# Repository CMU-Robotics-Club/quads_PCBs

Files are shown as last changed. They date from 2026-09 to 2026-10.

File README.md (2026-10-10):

# quads_PCBs

PCB designs for Laika, the CMU Robotics Club quadruped. Software lives in
[Laika-Software](https://github.com/CMU-Robotics-Club/Laika-Software).

Firmware lives in [quads_firmware](https://github.com/CMU-Robotics-Club/quads_firmware/tree/main). This repo might move to there into a subfolder

EDA tool: **KiCad**.

> [!IMPORTANT]
> Install git lfs: `sudo apt install git-lfs` or `brew install git-lfs`
> Run `git pull && git lfs lock Quads_MCU_PCB/*` when you want to edit the pcb, make your changes and push them, and then run `git lfs unlock Quads_MCU_PCB/*`. 
>
> This ensures that only 1 person can edit the pcb at a time. **REMEMBER TO PULL FROM REMOTE BEFORE YOU START WORKING, AND RELEASE THE LOCK WHEN YOU FINISH WORKING AND PUSH** 
>
> If you don't release the lock, we may forcefully retrieve the lock, causing your local changes to be broken and unpushable.

## System overview

TODO

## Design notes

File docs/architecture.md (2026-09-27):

# Mainboard architecture

Status: **draft**.

## Scope

The mainboard replaces the Nucleo-H723ZG and breakout modules with one PCB:

- STM32H723 MCU
- 3 CAN buses to the motors (on-chip FDCAN1–3), with CAN-FD capable
  transceivers (≥ 5 Mbps)
- USB to the Jetson Orin Nano
- IMU
- E-stop / power switch input
- Power: its own supply from the battery (5 V / 3.3 V), not from the Jetson

Not on this board: the motors, the Jetson, and motor power. Motors get power
straight from the battery.

## Motors

- 12× CubeMars AK80-8 KV30 motors, 3 per leg
- Each motor has an ODrive S1 driver
- Protocol: ODrive CAN, classic CAN frames
  ([code](https://github.com/CMU-Robotics-Club/Laika-Software/blob/dd9dcf645790c05628127b254bd854ea58fc05dc/laika_ws/src/laika_hardware_interface/odrive_base/src/socket_can.cp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)),
  1 Mbps
  ([code](https://github.com/CMU-Robotics-Club/Laika-Software/blob/dd9dcf645790c05628127b254bd854ea58fc05dc/laika_ws/src/laika_hardware_interface/hardware/laika_hardware_inter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))
- ODrive S1 supports CAN-FD from firmware 0.6.10
  ([ODrive docs](https://docs.odriverobotics.com/v/latest/hardware/odrive-comparison.html)).
  Laika-Software currently uses classic CAN.

## Control rate

**1 kHz.** [Laika-Software](https://github.com/CMU-Robotics-Club/Laika-Software)
runs its controllers at
[`update_rate: 1000`](https://github.com/CMU-Robotics-Club/Laika-Software/blob/dd9dcf645790c05628127b254bd854ea58fc05dc/laika_ws/src/laika_pid_controller/config/real_leg_pid_controller_co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).

Every cycle, for each motor:

- Host sends 3 frames:
  [`Set_Input_Torque`](https://github.com/CMU-Robotics-Club/Laika-Software/blob/dd9dcf645790c05628127b254bd854ea58fc05dc/laika_ws/src/laika_hardware_interface/hardware/laika_hardware_inter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) (torque command),
  [`Get_Torques`](https://github.com/CMU-Robotics-Club/Laika-Software/blob/dd9dcf645790c05628127b254bd854ea58fc05dc/laika_ws/src/laika_hardware_interface/hardware/laika_hardware_inter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) and
  [`Get_Encoder_Estimates`](https://github.com/CMU-Robotics-Club/Laika-Software/blob/dd9dcf645790c05628127b254bd854ea58fc05dc/laika_ws/src/laika_hardware_interface/hardware/laika_hardware_inter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) (requests)
- Host receives 2 replies: torque, and position/velocity
  ([code](https://github.com/CMU-Robotics-Club/Laika-Software/blob/dd9dcf645790c05628127b254bd854ea58fc05dc/laika_ws/src/laika_hardware_interface/hardware/laika_hardware_inter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))

The ODrive also sends `Heartbeat` frames ([code](https://github.com/CMU-Robotics-Club/Laika-Software/blob/dd9dcf645790c05628127b254bd854ea58fc05dc/laika_ws/src/laika_hardware_interface/hardware/laika_hardware_inter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)) at a rate set in
the ODrive config.

## CAN bus plan

Grouped by joint type, 4 motors per bus:

| Bus | Controller | Motors |
|---|---|---|
| CAN1 | FDCAN1 | 4× hip ab/ad (one per leg) |
| CAN2 | FDCAN2 | 4× thigh |
| CAN3 | FDCAN3 | 4× knee |

Wiring: each bus runs from motor to motor in a chain, with a 120 Ω resistor
at both ends (one on this board, one at the last motor).

## Jetson link

USB Full-Speed.

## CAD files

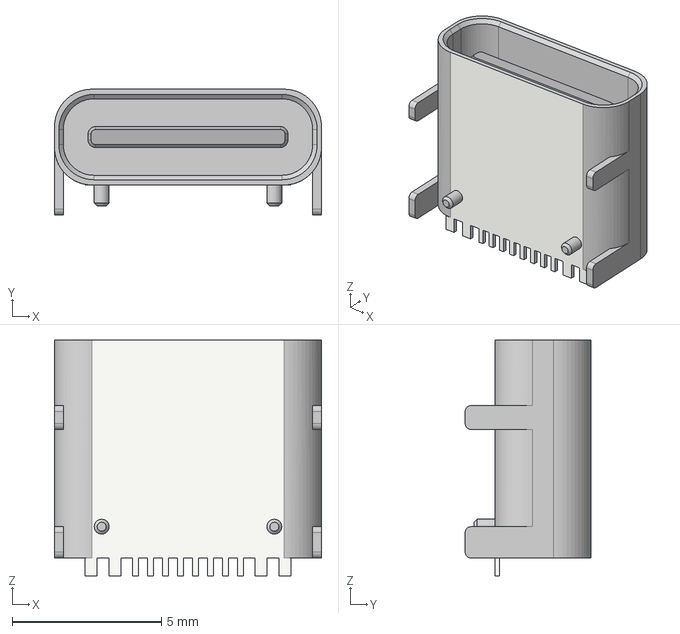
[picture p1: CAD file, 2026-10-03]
Quads_MCU_PCB/3d_models/USB_C_Receptacle_HRO_TYPE-C-31-M-12.step
8.94 x 4.21 x 7.90 mm

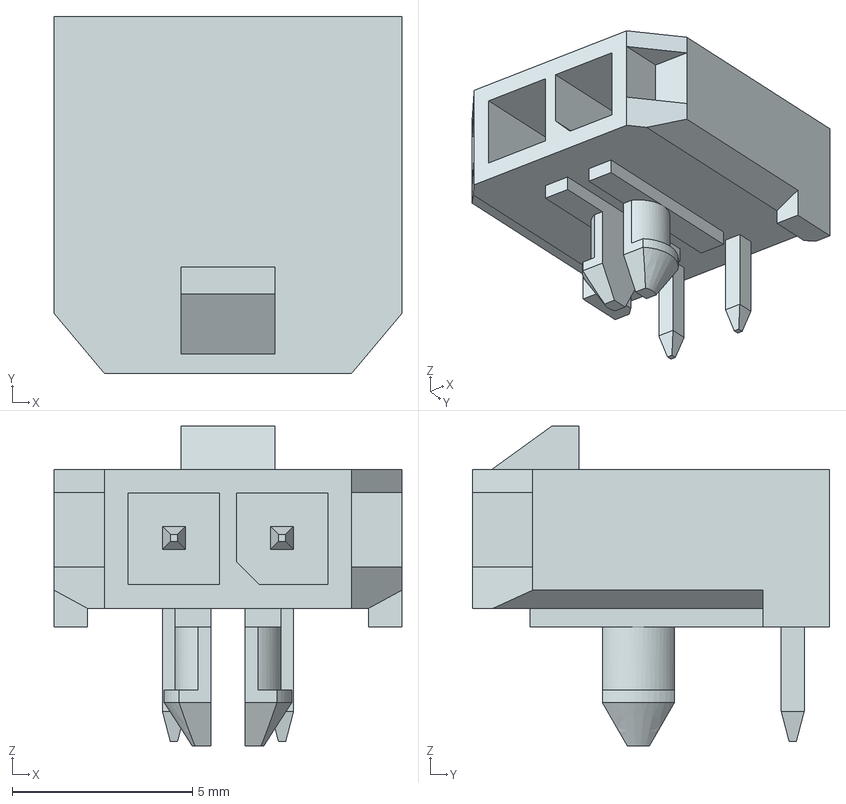
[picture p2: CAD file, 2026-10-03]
Quads_MCU_PCB/3d_models/436500200.stp
9.65 x 9.90 x 8.87 mm

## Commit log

2026-09-27 Add mainboard architecture spec and repo scaffold
    - README with board list and system block diagram
    - docs/architecture.md: 3 CAN buses grouped by joint type (4x AK80-8
    per bus, classic CAN 1 Mbps, 500 Hz), MCP2518FD footprint reserved,
    open questions
    - KiCad .gitignore
2026-09-27 Drop reserved 4th CAN bus; 3 on-chip FDCAN at 500 Hz is sufficient
2026-09-27 Correct target control rate to 1 kHz
    The 500 Hz target was derived from bus bandwidth and justified by assuming
    MIT-mode PD inside the motor. Laika-Software actually runs controllers at
    update_rate: 1000 with host-side PID sending torque every cycle, and uses
    the ODrive CAN protocol. Mark the 3-bus plan as not meeting 1 kHz and the
    motor driver/protocol as unconfirmed.
2026-09-27 Remove MIT mode assumption; state frame-count assumption explicitly
2026-09-27 Phrase CAN-FD support as open question; drop duplicate frame-count line
2026-09-27 Rewrite architecture doc in plain language, confirmed facts only
    - Motors use ODrive drivers (ODrive CAN, classic frames, 1 Mbps)
    - Control rate 1 kHz with per-cycle frame list linked to source
    - Remove estimates and open questions
2026-09-27 Keep only code-confirmed frames; drop inferred replies
2026-09-27 Specify ODrive S1 drivers and CAN-FD capable transceivers
    - ODrive S1 supports CAN-FD from firmware 0.6.10 (ODrive docs)
    - Require CAN-FD transceivers so the board works with classic CAN now
    and CAN-FD later without a respin
2026-09-27 Document received frames per cycle and ODrive heartbeat
2026-10-01 Added board
    [Quads_MCU_PCB.kicad_pcb, Quads_MCU_PCB.kicad_sch]
2026-10-01 Replaced tcan4550 with MCP2518FD
    [Quads_MCU_PCB.kicad_sch]
2026-10-01 Added CAN Connectors
    [Quads_MCU_PCB.kicad_sch]
2026-10-01 Fixed the quartz clock
    [Quads_MCU_PCB.kicad_sch]
2026-10-01 Fixed some wiring issues
    [Quads_MCU_PCB.kicad_sch]
2026-10-02 Fixed CAN pin connections
    [Quads_MCU_PCB.kicad_sch]
2026-10-02 Fixed VBUS voltage divider
    [Quads_MCU_PCB.kicad_sch]
2026-10-02 Switched to active oscillators and added MCU clock
    [Quads_MCU_PCB.kicad_sch]
2026-10-02 Fixed ERC tests
    [Quads_MCU_PCB.kicad_sch]
2026-10-02 Removed old text
    [Quads_MCU_PCB.kicad_sch]
2026-10-02 Add BMI088 IMU on SPI4
    U10 BMI088 (Sensor_Motion:BMI088, Bosch LGA-16) wired per datasheet
    Fig. 8 (SPI mode):
    - SPI4: PE2 SCK, PE5 MISO (SDO1 + SDO2), PE6 MOSI
    - Chip selects as GPIO: PE3 -> CSB1 (accel), PE4 -> CSB2 (gyro)
    - Data-ready interrupts: PE7 <- INT1 (accel), PE8 <- INT3 (gyro)
    - PS tied to GND (selects SPI); INT2/INT4 left unconnected
    - C59/C60 100nF decoupling on VDD/VDDIO, both from +3V3
    - Removed the no-connect flags on PE2-PE8
    SPI4 is separate from SPI1 so IMU reads don't compete with MCP2518FD
    CAN traffic. ERC adds one expected pin_to_pin error: SDO1/SDO2 are both
    "output" but tri-state when their CS is high, as in Bosch Fig. 8.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
    [Quads_MCU_PCB.kicad_sch]
2026-10-02 Assign footprints and LCSC part numbers for JLC assembly
    0402 for small passives, 0603 for 4.7uF/10uF, 1206 for 47uF on 5V
    rails, 1210 25V for C27 on +12V. Polyfuse is 1812 33V (1206 polyfuses
    are only rated 6-8V). Added a hidden "LCSC" field per part; every
    number was checked on jlcpcb.com (value, voltage, package,
    basic/extended).
    Not yet assigned:
    - J2-J7 connectors (J4-J7 to become JST GH 4-pin to match ODrive S1)
    - U3/U6/U7/U9 ISOW1044: out of stock at JLC
    - Y1/Y2 oscillators, SW1
    Netlist connectivity verified unchanged before/after.
    [Quads_MCU_PCB.kicad_sch]
2026-10-02 Switch CAN connectors J4-J7 to JST GH 4-pin to match ODrive S1
    ODrive S1 J16/J17 is JST GH 4-pin (SM04B-GHS-TB). Pinout from the S1
    datasheet: 1 = 12V IN (optional logic power), 2 = CAN_H, 3 = CAN_L,
    4 = GND (not connected inside the ODrive). Matching it lets us use
    straight 1:1 GH cables.
    New pinout on J4-J7:
    - Pin 1: NC (ODrive's 12V IN; we don't supply CAN power)
    - Pin 2: CANH
    - Pin 3: CANL
    - Pin 4: GND2 (isolated side of the ISOW1044, so CAN stays
    galvanically isolated from the main board)
    Footprint JST_GH_SM04B-GHS-TB_1x04-1MP_P1.25mm_Horizontal, LCSC
    C189895. The symbol was flipped and shifted so the existing wires are
    unchanged; netlist verified: only the J4-J7 pin numbers changed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
    [Quads_MCU_PCB.kicad_sch]
2026-10-02 Assign footprints for J3 power input and J2 SWD header
    - J3 (12V in): Molex Micro-Fit 3.0 43045-0212, 2x01 vertical THT with
    pegs, as Advaith picked Micro-Fit 3.0. Pad 1 = 12V in, pad 2 = GND.
    LCSC C293362 (genuine Molex).
    - J2 (SWD): generic 2.54mm 1x6 vertical header for now, since the
    debugger isn't chosen yet; jumpers fit any probe. LCSC C492405.
    Every part now has a footprint. Still missing LCSC numbers: U3/U6/U7/U9
    (ISOW1044, out of stock at JLC), Y1/Y2, SW1.
    [Quads_MCU_PCB.kicad_sch]
2026-10-02 Add LCSC part numbers for Y1, Y2 and SW1
    Y1 40 MHz: C2831396 (YXC OT322540MJBA4SL)
    Y2 25 MHz: C669088 (YXC OT322525MJBA4SL)
    3.3 V CMOS, 3225 4-pin, duty cycle 45-55% per datasheet
    (MCP2518FD requires 45-55% on OSC1). Pinout matches the ASE footprint.
    SW1: C273528 (E-Switch TL3301NF260QG), matches the TL3301NxxxxxG footprint.
    KiCad also re-sorted no_connect entries on save; no other changes.
    [Quads_MCU_PCB.kicad_sch]
2026-10-02 Replace out-of-stock ISOW1044 with ADM3057E on all four CAN channels
    ISOW1044 is out of stock at TI until 2027. ADM3057ExRW (3 kV, SOIC-20W,
    LCSC C658109) is pin-compatible enough to swap in place on U3/U6/U7/U9.
    Per channel, following the ADM3055E/ADM3057E datasheet:
    - SILENT, STBY, AUXIN tied to GND; AUXOUT not connected
    - RS tied to GND2 (full-speed mode)
    - Ferrite beads (BLM15HD182SN1D, C76888) between VISOOUT/VISOIN and
    GNDISO/GND2 to contain the 180 MHz isoPower switching noise
    - Decoupling: VCC 10u+100n, VIO 100n+10n, VISOIN 100n+10n,
    VISOOUT 10u+220n returned to GNDISO (local label <U>_GNDISO)
    New parts: C61-C68, FB1-FB8. Netlist checked per channel: TXD/RXD,
    CANH/CANL and J pi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
    [Quads_MCU_PCB.kicad_sch]
2026-10-02 Fixed ERC output pin issue
    [Quads_MCU_PCB.kicad_sch]
2026-10-02 Fixed debug pin order
    [Quads_MCU_PCB.kicad_sch]
2026-10-02 Added a debug led to PE1
    [Quads_MCU_PCB.kicad_sch]
2026-10-02 did some layout stuff
    [Quads_MCU_PCB.kicad_pcb]
2026-10-03 Updated pwr connector footprint & added 3d model
    [436500200.stp, Quads_MCU_PCB.kicad_pcb, Quads_MCU_PCB.kicad_sch]
2026-10-03 Updated molex connector position
    [Quads_MCU_PCB.kicad_pcb]
2026-10-03 Cleaned up layout a bit
    [Quads_MCU_PCB.kicad_pcb]
2026-10-03 Added USBC 3d model
    [Quads_MCU_PCB.kicad_pcb, USB_C_Receptacle_HRO_TYPE-C-31-M-12.step]
2026-10-03 Layout: General positions
    [Quads_MCU_PCB.kicad_pcb, Quads_MCU_PCB.kicad_sch]
2026-10-05 Added file locking
    [Quads_MCU_PCB.kicad_pcb, Quads_MCU_PCB.kicad_sch]
2026-10-07 Added pin breakout
    [Quads_MCU_PCB.kicad_pcb, Quads_MCU_PCB.kicad_sch]
2026-10-08 Added some decoupling caps
    [Quads_MCU_PCB.kicad_pcb]
2026-10-09 Added DRC and more dec caps
    [Quads_MCU_PCB.kicad_pcb]
2026-10-10 Small scale routing + DRC
    [Quads_MCU_PCB.kicad_pcb, Quads_MCU_PCB.kicad_sch]
2026-10-11 Fixed ADM3057 schematic issues
2026-10-21 Updated silkscreen
